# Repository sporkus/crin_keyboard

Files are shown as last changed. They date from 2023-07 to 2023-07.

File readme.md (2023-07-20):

# Crin keyboard PCB
-----------

Open sourced replacement PCB for [crin keyboard](https://cannonkeys.com/products/gb-crin-keyboard)

## Fabrication
* verified production files can be found [here](./pcb_production)

## Plate
Plate files can be found here:
https://github.com/cBachoo/bachooKeyboardFiles/tree/master/Crin/CrinPlateFiles

## Misc
#### layout
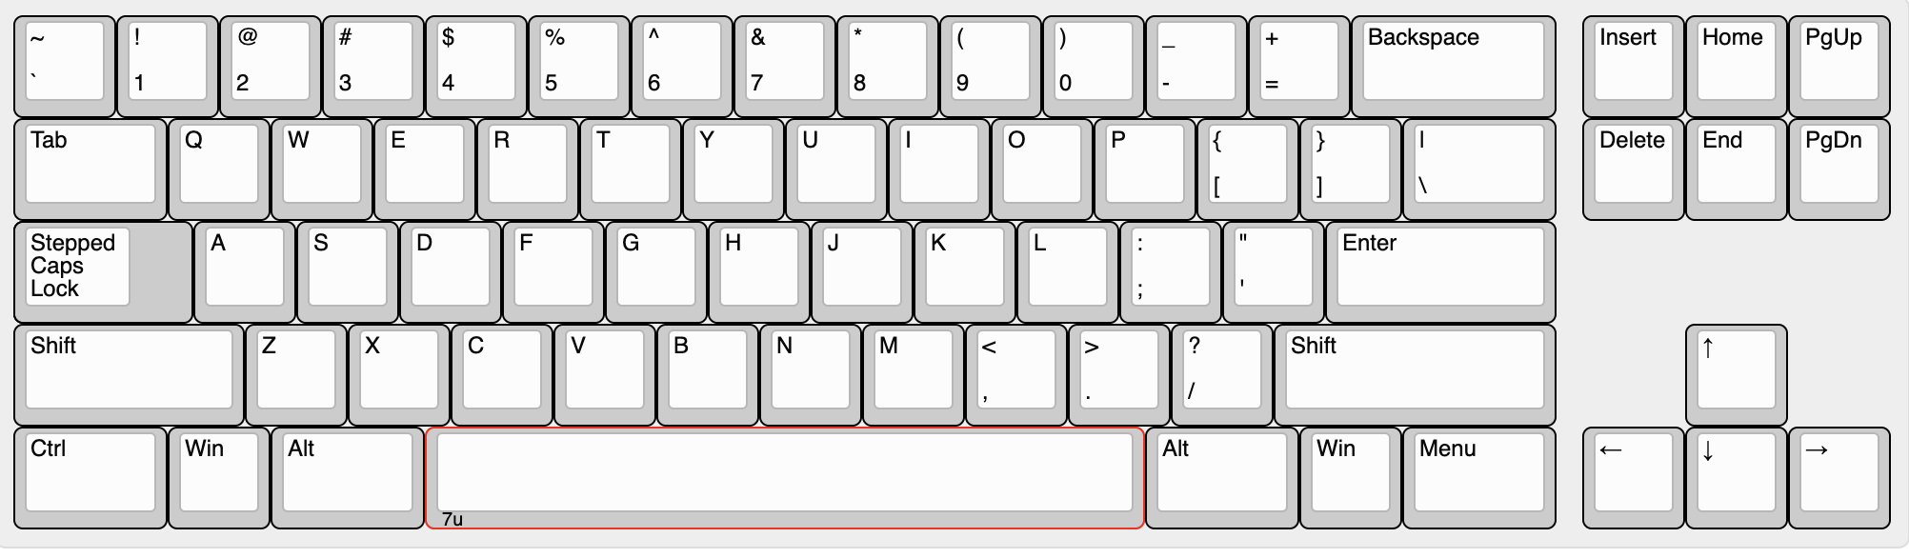
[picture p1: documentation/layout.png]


#### PCB renders
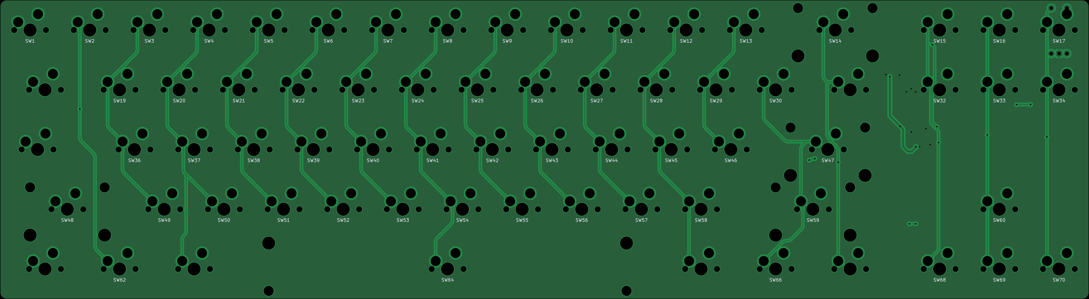
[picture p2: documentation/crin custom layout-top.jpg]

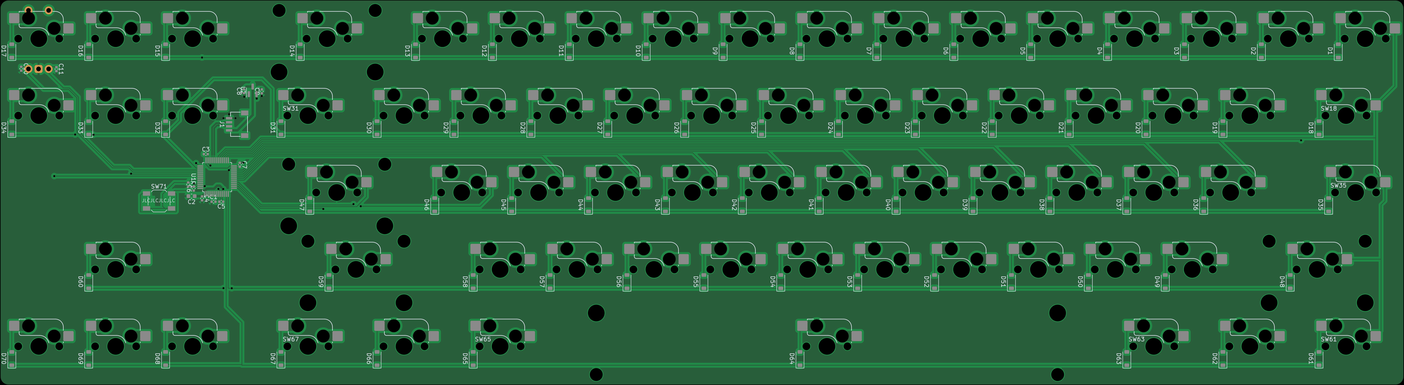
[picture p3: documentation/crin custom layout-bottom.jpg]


#### Interactive BoM
download this [html](<./documentation/crin custom layout-ibom.html>) and run locally

#### Schematic
[pdf](<./documentation/crin custom layout-schematic.pdf>)

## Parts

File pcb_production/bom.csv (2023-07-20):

Designator | Footprint | Quantity | Value | LCSC Part #
C1, C10, C11, C3, C4, C5, C6, C7 | 0402 | 8 | 100nF | C307331
C2 | 0603 | 1 | 10uF 25V
C8, C9 | 0402 | 2 | 1uF | C52923
D1, D10, D11, D12, D13, D14, D15, D16, D17, D18, D19, D2, D20, D21, D22, D23, D24, D25, D26, D27, D28, D29, D3, D30, D31, D32, D33, D34, D35, D36, D37, D38, D39, D4, D40, D41, D42, D43, D44, D45, D46, D47, D48, D49, D5, D50, D51, D52, D53, D54, D55, D56, D57, D58, D59, D6, D60, D61, D62, D63, D64, D65, D66, D67, D68, D69, D7, D70, D8, D9 | D_SOD-123 | 70 | 1N4148W
J1 | JST-SR-4 | 1 | SM04B-SRSS-TB(LF)(SN)
R1 | 0402 | 1 | 10k
SW1, SW10, SW11, SW12, SW13, SW14, SW15, SW16, SW17, SW19, SW2, SW20, SW21, SW22, SW23, SW24, SW25, SW26, SW27, SW28, SW29, SW3, SW30, SW32, SW33, SW34, SW36, SW37, SW38, SW39, SW4, SW40, SW41, SW42, SW43, SW44, SW45, SW46, SW47, SW48, SW49, SW5, SW50, SW51, SW52, SW53, SW54, SW55, SW56, SW57, SW58, SW59, SW6, SW60, SW62, SW64, SW66, SW68, SW69, SW7, SW70, SW8, SW9 | SW_MX_HS_1u | 63 | MX
SW18, SW31, SW61, SW63, SW65, SW67 | SW_MX_HS_1.5u | 6 | MX
SW35 | SW_MX_HS_1.75u_STP_1.25 | 1 | MX
SW71 | SW_SPST_SKQG_WithoutStem | 1 | SKQGABE010
SW73 | ROT_Alps_EC11E-Switch | 1 | Rotary_Encoder_Switch
U1 | LQFP-48_7x7mm_P0.5mm | 1 | STM32F072C8T6
U2 | SOT-23 | 1 | XC6206PxxxMR-Regulator_Linear | C5446

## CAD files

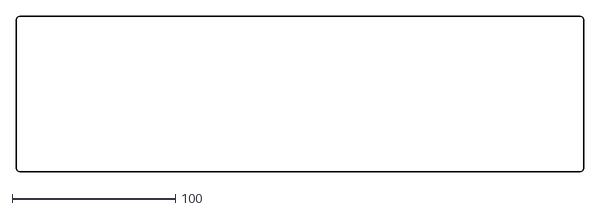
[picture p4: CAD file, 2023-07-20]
documentation/crin custom layout-Edge_Cuts.dxf
347.7 x 95.2

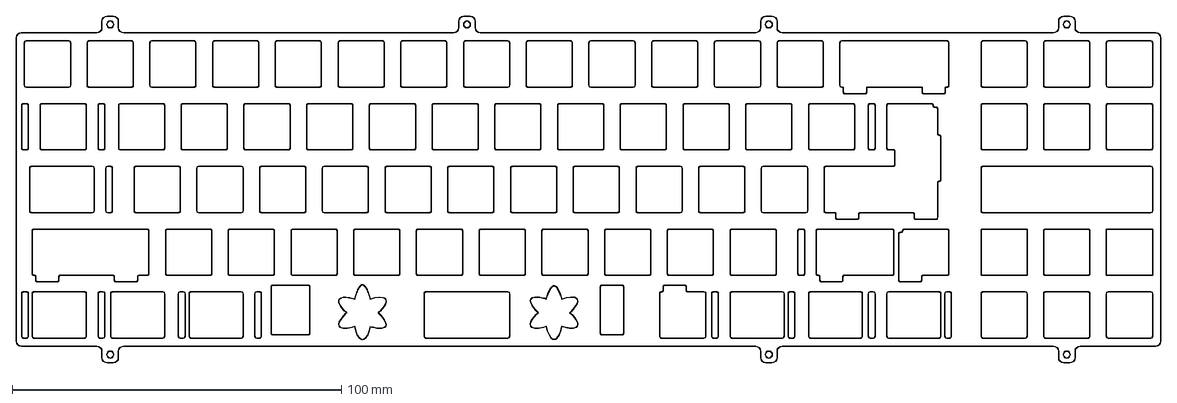
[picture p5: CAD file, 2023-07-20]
documentation/crin_plate.DXF
347.7 x 105.3 mm

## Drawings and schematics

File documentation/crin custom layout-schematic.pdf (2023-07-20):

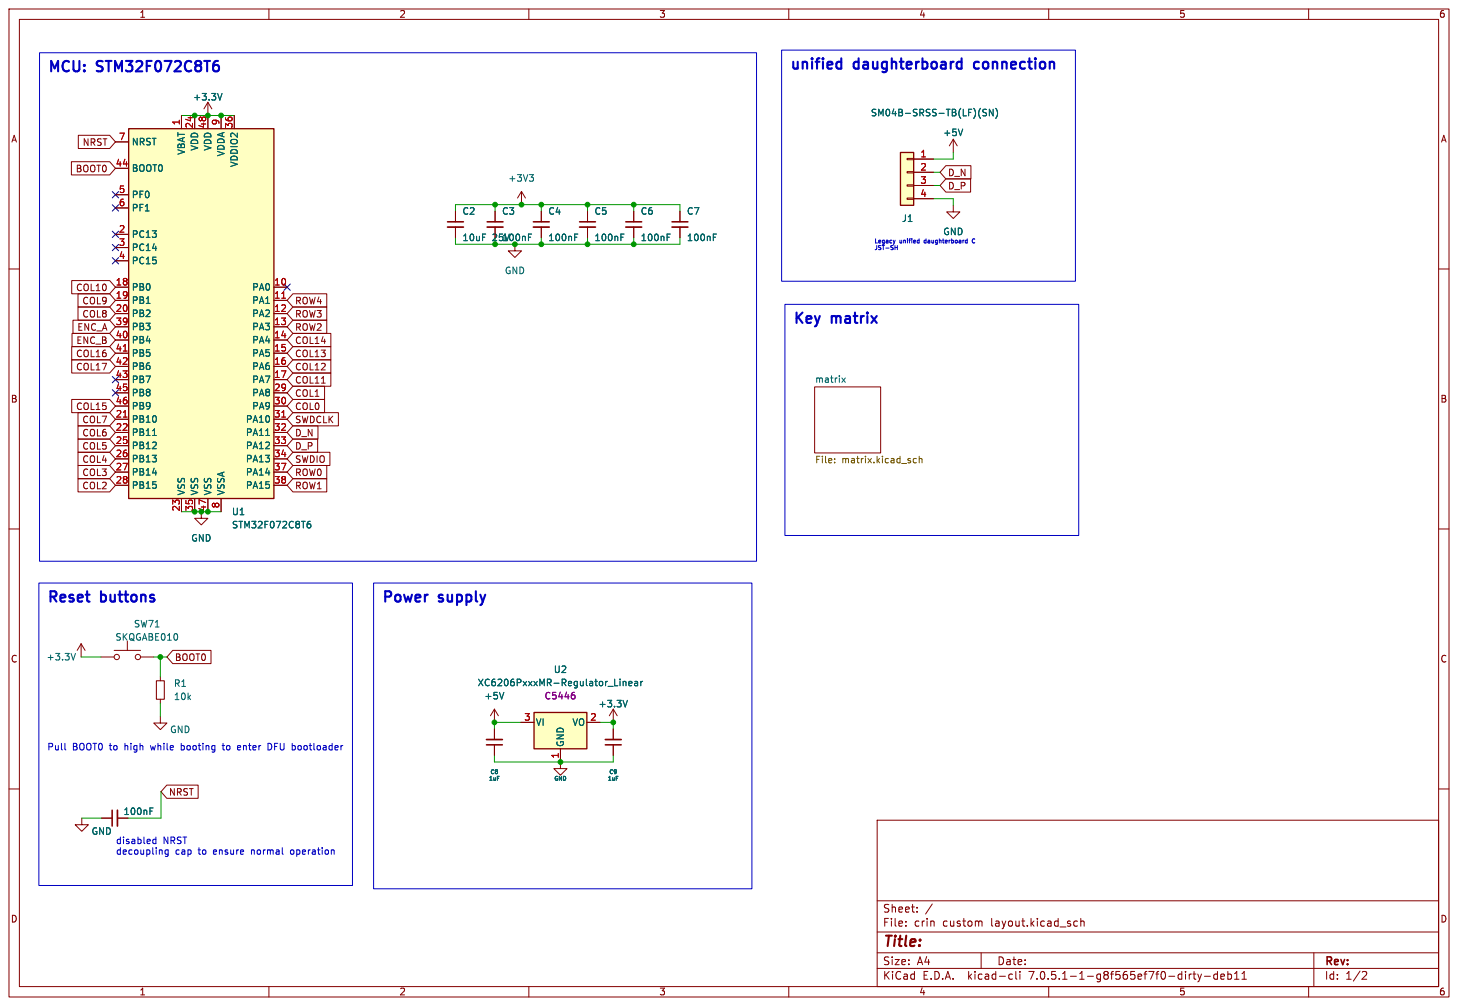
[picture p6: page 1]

J1 SM04B-SRSS-TB(LF)(SN) +5V GND

J1 SM04B-SRSS-TB(LF)(SN) 1

1 PA0 10 PA1 11 PA2 12 PA3 13 PA4 14 PA5 15 PA6 16 PA7 17 PB0 18 PB1 19 PC13 2 PB2 20 PB10 21 PB11 22 VSS 23 VDD 24 PB12 25 PB13 26 PB14 27 PB15 28 PA8 29 PC14 3 PA9 30 PA10 31 PA11 32 PA12 33 PA13 34 VSS 35 VDDIO2 36 PA14 37 PA15 38 PB3 39 PC15 4 PB4 40 PB5 41 PB6 42 PB7 43 BOOT0 44 PB8 45 PB9 46 VSS 47 VDD 48 PF0 5 PF1 6 NRST 7 VSSA

Id: 1/2 Title: File: crin custom layout.kicad_sch Sheet: / matrix File: matrix.kicad_sch C3

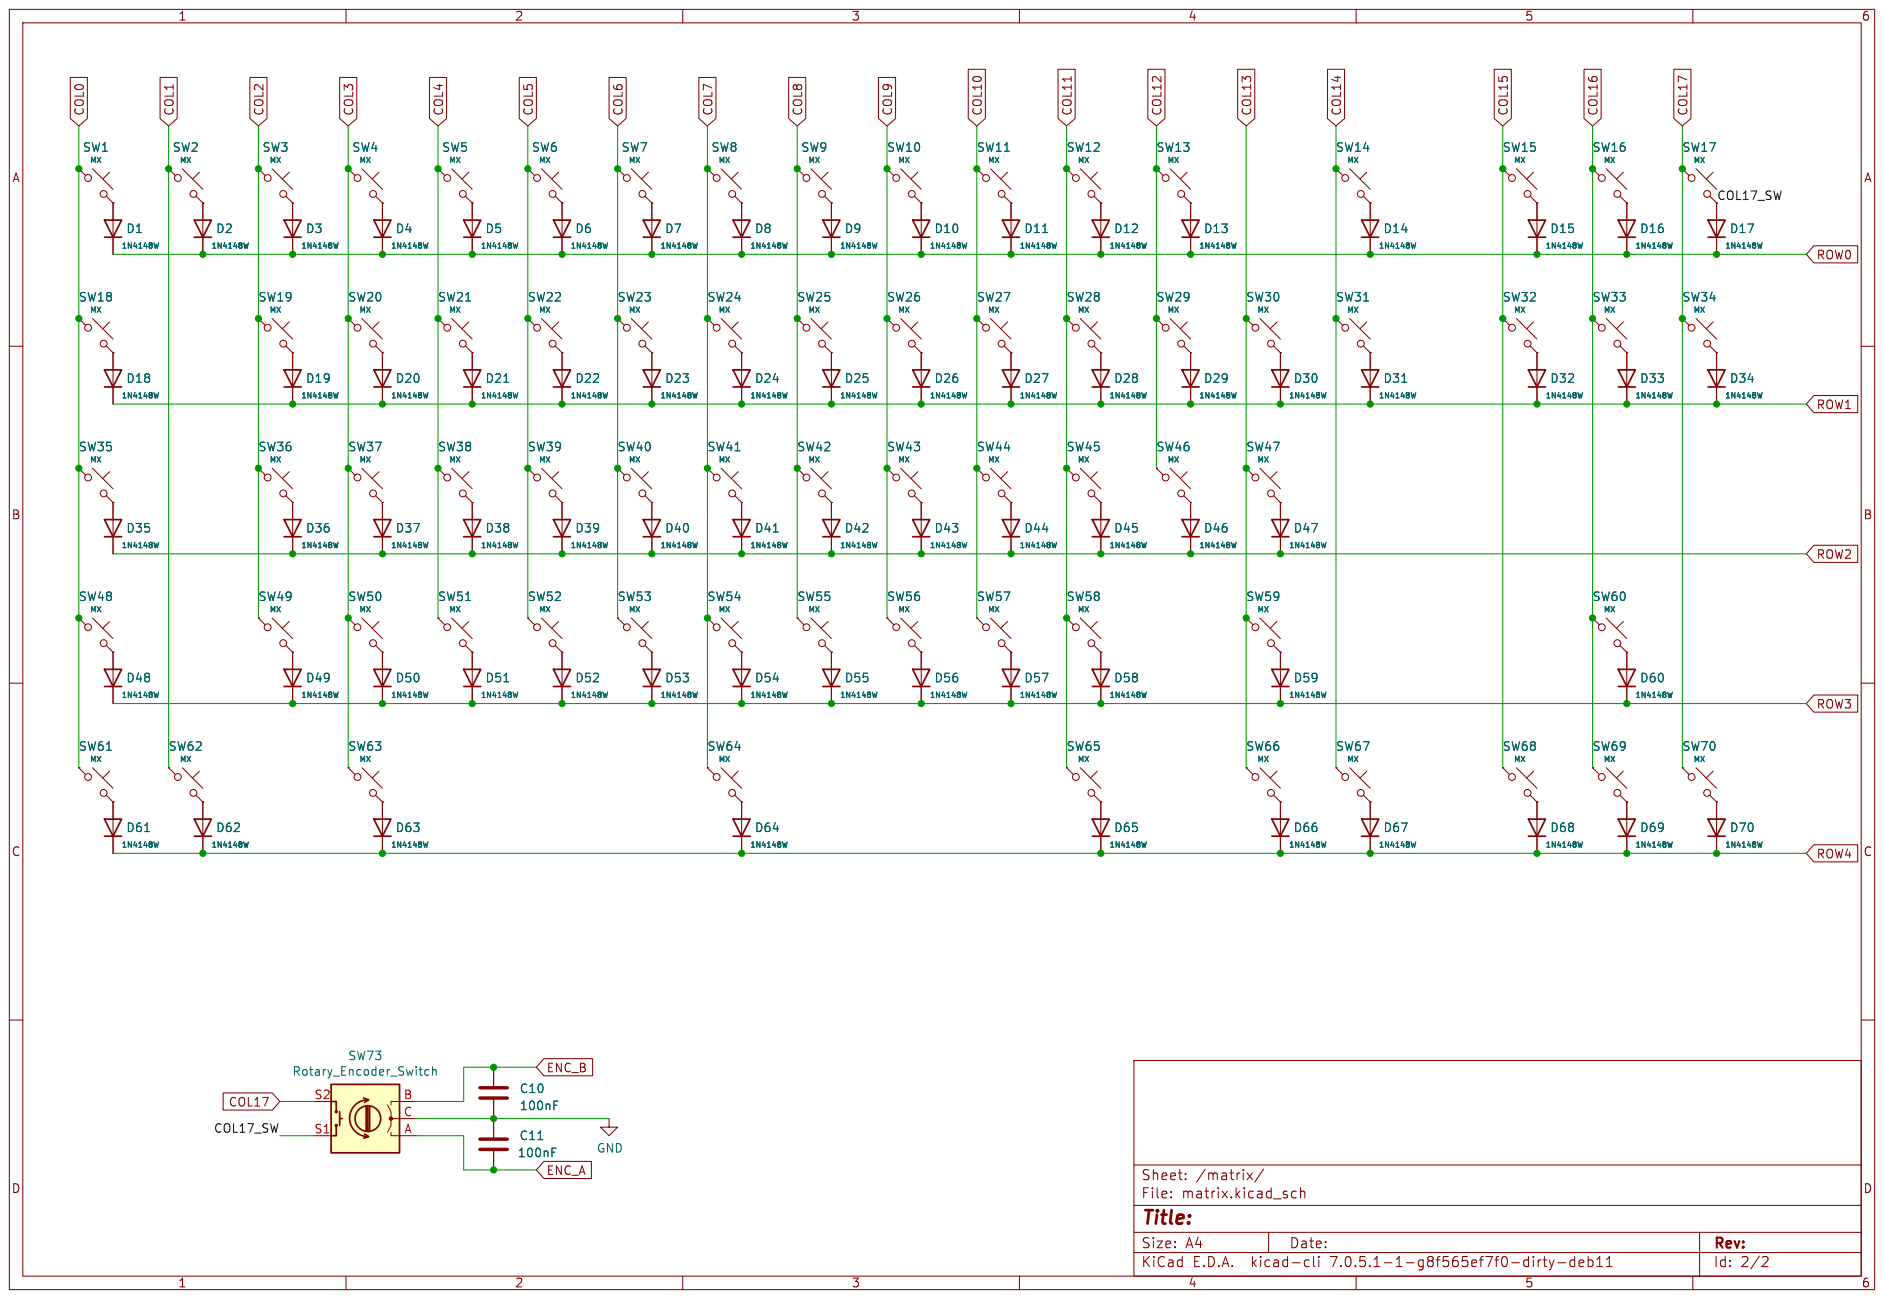
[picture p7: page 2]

Id: 2/2 Title: File: matrix.kicad_sch Sheet: /matrix/

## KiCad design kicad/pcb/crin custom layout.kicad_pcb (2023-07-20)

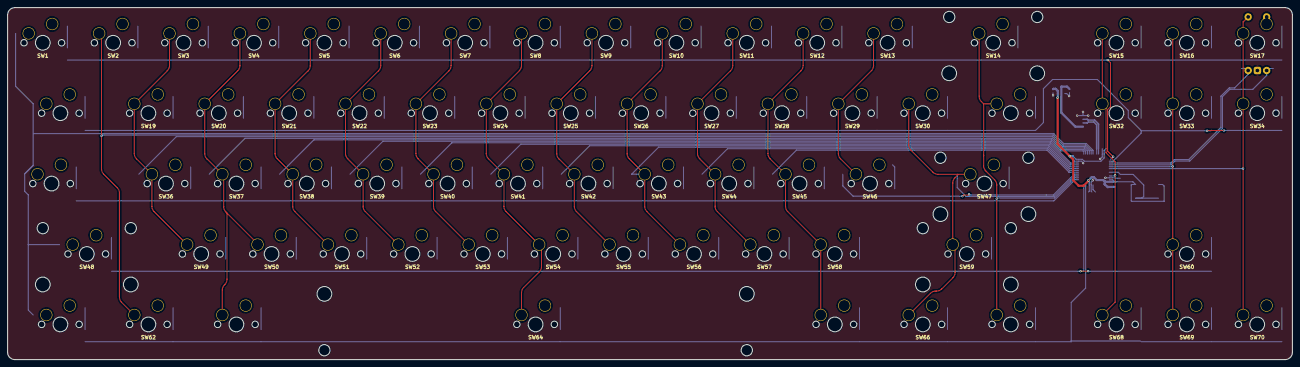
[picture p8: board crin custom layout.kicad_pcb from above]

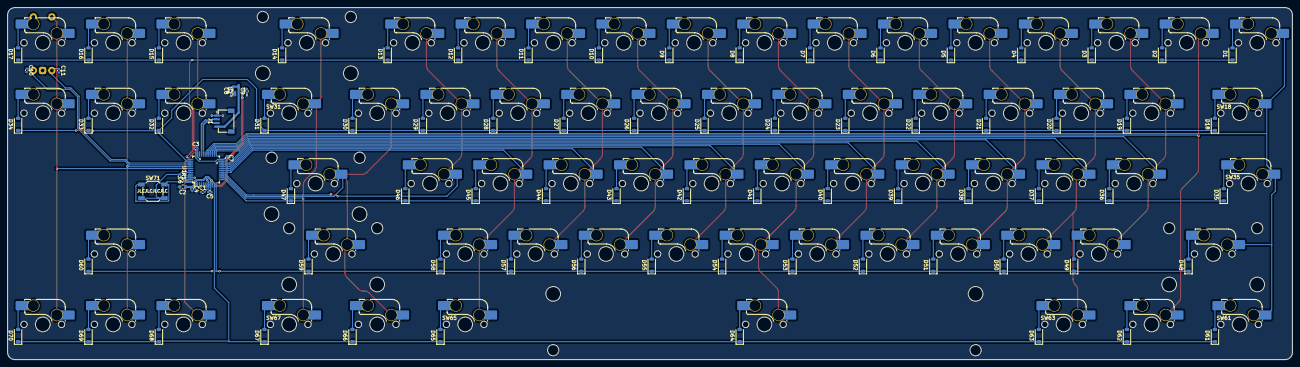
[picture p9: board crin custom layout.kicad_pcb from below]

Board: 2 copper layers, 347.7 x 95.2 mm, 157 parts (156 on the bottom side), 102 nets.

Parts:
C1, C3, C4, C5, C6, C7, C10, C11: 100nF; C_0402_1005Metric
C2: 10uF 25V; C_0603_1608Metric
C8, C9: 1uF; C_0402_1005Metric
D1, D2, D3, D4, D5, D6, D7, D8, D9, D10, D11, D12, D13, D14, D15, D16, D17, D18, D19, D20, D21, D22, D23, D24, D25, D26, D27, D28, D29, D30, D31, D32, D33, D34, D35, D36, D37, D38, D39, D40, D41, D42, D43, D44, D45, D46, D47, D48, D49, D50, D51, D52, D53, D54, D55, D56, D57, D58, D59, D60, D61, D62, D63, D64, D65, D66, D67, D68, D69, D70: 1N4148W; D_SOD-123
J1: SM04B-SRSS-TB(LF)(SN); JST-SR-4
R1: 10k; R_0402_1005Metric
SW1, SW2, SW3, SW4, SW5, SW6, SW7, SW8, SW9, SW10, SW11, SW12, SW13, SW14, SW15, SW16, SW17, SW19, SW20, SW21, SW22, SW23, SW24, SW25, SW26, SW27, SW28, SW29, SW30, SW32, SW33, SW34, SW36, SW37, SW38, SW39, SW40, SW41, SW42, SW43, SW44, SW45, SW46, SW47, SW48, SW49, SW50, SW51, SW52, SW53, SW54, SW55, SW56, SW57, SW58, SW59, SW60, SW62, SW64, SW66, SW68, SW69, SW70: MX; SW_MX_HS_1u
SW18, SW31, SW61, SW63, SW65, SW67: MX; SW_MX_HS_1.5u
SW35: MX; SW_MX_HS_1.75u_STP_1.25
SW71: SKQGABE010; SW_SPST_SKQG_WithoutStem
SW73: Rotary_Encoder_Switch; ROT_Alps_EC11E-Switch
U1: STM32F072C8T6; LQFP-48_7x7mm_P0.5mm
U2: XC6206PxxxMR-Regulator_Linear; SOT-23

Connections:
+3V3: C2.1, C3.1, C4.1, C5.1, C6.1, C7.1, C9.2, SW71.1, U1.1 (VBAT), U1.9 (VDDA), U1.24 (VDD), U1.36 (VDDIO2), U1.48 (VDD), U2.2 (VO)
+5V: C8.2, J1.1, U2.3 (VI)
/matrix/COL17_SW: D17.2 (A), SW17.2, SW73.S1
BOOT0: R1.1, SW71.2, U1.44 (BOOT0)
COL0: SW1.1, SW18.1, SW35.1, SW48.1, SW61.1, U1.30 (PA9)
COL1: SW2.1, SW62.1, U1.29 (PA8)
COL2: SW3.1, SW19.1, SW36.1, SW49.1, U1.28 (PB15)
COL3: SW4.1, SW20.1, SW37.1, SW50.1, SW63.1, U1.27 (PB14)
COL4: SW5.1, SW21.1, SW38.1, SW51.1, U1.26 (PB13)
COL5: SW6.1, SW22.1, SW39.1, SW52.1, U1.25 (PB12)
COL6: SW7.1, SW23.1, SW40.1, SW53.1, U1.22 (PB11)
COL7: SW8.1, SW24.1, SW41.1, SW54.1, SW64.1, U1.21 (PB10)
COL8: SW9.1, SW25.1, SW42.1, SW55.1, U1.20 (PB2)
COL9: SW10.1, SW26.1, SW43.1, SW56.1, U1.19 (PB1)
COL10: SW11.1, SW27.1, SW44.1, SW57.1, U1.18 (PB0)
COL11: SW12.1, SW28.1, SW45.1, SW58.1, SW65.1, U1.17 (PA7)
COL12: SW13.1, SW29.1, SW46.1, U1.16 (PA6)
COL13: SW30.1, SW47.1, SW59.1, SW66.1, U1.15 (PA5)
COL14: SW14.1, SW31.1, SW67.1, U1.14 (PA4)
COL15: SW15.1, SW32.1, SW68.1, U1.46 (PB9)
COL16: SW16.1, SW33.1, SW60.1, SW69.1, U1.41 (PB5)
COL17: SW17.1, SW34.1, SW70.1, SW73.S2, U1.42 (PB6)
D_N: J1.2, U1.32 (PA11)
D_P: J1.3, U1.33 (PA12)
ENC_A: C11.1, SW73.A, U1.39 (PB3)
ENC_B: C10.1, SW73.B, U1.40 (PB4)
GND: C1.1, C2.2, C3.2, C4.2, C5.2, C6.2, C7.2, C8.1, C9.1, C10.2, C11.2, J1.4, R1.2, SW73.C, U1.8 (VSSA), U1.23 (VSS), U1.35 (VSS), U1.47 (VSS), U2.1 (GND)
NRST: C1.2, U1.7 (NRST)
unnamed: D1.2 (A), SW1.2
unnamed: D2.2 (A), SW2.2
unnamed: D3.2 (A), SW3.2
unnamed: D4.2 (A), SW4.2
unnamed: D5.2 (A), SW5.2
unnamed: D6.2 (A), SW6.2
unnamed: D7.2 (A), SW7.2
unnamed: D8.2 (A), SW8.2
unnamed: D9.2 (A), SW9.2
unnamed: D10.2 (A), SW10.2
unnamed: D11.2 (A), SW11.2
unnamed: D12.2 (A), SW12.2
unnamed: D13.2 (A), SW13.2
unnamed: D14.2 (A), SW14.2
unnamed: D15.2 (A), SW15.2
unnamed: D16.2 (A), SW16.2
unnamed: D18.2 (A), SW18.2
unnamed: D19.2 (A), SW19.2
unnamed: D20.2 (A), SW20.2
unnamed: D21.2 (A), SW21.2
unnamed: D22.2 (A), SW22.2
unnamed: D23.2 (A), SW23.2
unnamed: D24.2 (A), SW24.2
unnamed: D25.2 (A), SW25.2
unnamed: D26.2 (A), SW26.2
unnamed: D27.2 (A), SW27.2
unnamed: D28.2 (A), SW28.2
unnamed: D29.2 (A), SW29.2
unnamed: D30.2 (A), SW30.2
unnamed: D31.2 (A), SW31.2
unnamed: D32.2 (A), SW32.2
unnamed: D33.2 (A), SW33.2
unnamed: D34.2 (A), SW34.2
unnamed: D35.2 (A), SW35.2
unnamed: D36.2 (A), SW36.2
unnamed: D37.2 (A), SW37.2
unnamed: D38.2 (A), SW38.2
unnamed: D39.2 (A), SW39.2
unnamed: D40.2 (A), SW40.2
unnamed: D41.2 (A), SW41.2
unnamed: D42.2 (A), SW42.2
unnamed: D43.2 (A), SW43.2
unnamed: D44.2 (A), SW44.2
unnamed: D45.2 (A), SW45.2
unnamed: D46.2 (A), SW46.2
unnamed: D47.2 (A), SW47.2
unnamed: D48.2 (A), SW48.2
unnamed: D49.2 (A), SW49.2
unnamed: D50.2 (A), SW50.2
unnamed: D51.2 (A), SW51.2
unnamed: D52.2 (A), SW52.2
unnamed: D53.2 (A), SW53.2
unnamed: D54.2 (A), SW54.2
unnamed: D55.2 (A), SW55.2
unnamed: D56.2 (A), SW56.2
unnamed: D57.2 (A), SW57.2
unnamed: D58.2 (A), SW58.2
unnamed: D59.2 (A), SW59.2
unnamed: D60.2 (A), SW60.2
unnamed: D61.2 (A), SW61.2
unnamed: D62.2 (A), SW62.2
unnamed: D63.2 (A), SW63.2
unnamed: D64.2 (A), SW64.2
unnamed: D65.2 (A), SW65.2
unnamed: D66.2 (A), SW66.2
unnamed: D67.2 (A), SW67.2
unnamed: D68.2 (A), SW68.2
unnamed: D69.2 (A), SW69.2
unnamed: D70.2 (A), SW70.2
ROW0: D1.1 (K), D2.1 (K), D3.1 (K), D4.1 (K), D5.1 (K), D6.1 (K), D7.1 (K), D8.1 (K), D9.1 (K), D10.1 (K), D11.1 (K), D12.1 (K), D13.1 (K), D14.1 (K), D15.1 (K), D16.1 (K), D17.1 (K), U1.37 (PA14)
ROW1: D18.1 (K), D19.1 (K), D20.1 (K), D21.1 (K), D22.1 (K), D23.1 (K), D24.1 (K), D25.1 (K), D26.1 (K), D27.1 (K), D28.1 (K), D29.1 (K), D30.1 (K), D31.1 (K), D32.1 (K), D33.1 (K), D34.1 (K), U1.38 (PA15)
ROW2: D35.1 (K), D36.1 (K), D37.1 (K), D38.1 (K), D39.1 (K), D40.1 (K), D41.1 (K), D42.1 (K), D43.1 (K), D44.1 (K), D45.1 (K), D46.1 (K), D47.1 (K), U1.13 (PA3)
ROW3: D48.1 (K), D49.1 (K), D50.1 (K), D51.1 (K), D52.1 (K), D53.1 (K), D54.1 (K), D55.1 (K), D56.1 (K), D57.1 (K), D58.1 (K), D59.1 (K), D60.1 (K), U1.12 (PA2)
ROW4: D61.1 (K), D62.1 (K), D63.1 (K), D64.1 (K), D65.1 (K), D66.1 (K), D67.1 (K), D68.1 (K), D69.1 (K), D70.1 (K), U1.11 (PA1)
